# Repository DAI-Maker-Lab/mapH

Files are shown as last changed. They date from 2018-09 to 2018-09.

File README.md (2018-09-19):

<h1>mapH</h1>
mapH is a handheld georeferenced soil pH meter originally built as a demo for the 2018 Cracking the Nut conference. It was meant to illustrate potential applications of novel approaches to small-scale hardware development and production to climate smart agriculture in developing country contexts. It is based on the [DF Robot Analog Spear Tip pH sensor](https://www.dfrobot.com/product-1668.html), Arduino Pro Micro, and the Adafruit FONA 808.

It was just a proof-of-concept demo, so it's pretty rough. It uploads a CSV of the pH reading and the GPS coordinate to Pastebin where it can then be brought into a more useful analysis tool, like Mapbox or OpenGIS.

<h3>Usage</h3>
Turn the switch to the on position. When the green LED is lit and the red is off, the unit has a valid GPS fix and the user can take a sample. Place the soil probe into the soil to be sampled and press the button. The LEDs will flash while a series of 100 readings are very quickly taken and averaged. The red LED will light and the green will turn off, indicating that the reading is being transmitted to the server. When the green LED is lit, the unit is ready to take another sample.

<h3>Research Questions</h3>
mapH was developed as a demonstration of the potential of custom hardware to serve the needs of developing country users in the area of climate smart agriculture. It was developed on the hypothesis that awareness of the relative pH differences of farmers' fields could enable more efficient and effective application of fertilizers and other inputs. Similar tools, scaled for developed country farmers, are available commercially on the same principle (and a review of the literature on the effectiveness of these in practice would be interesting in itself).

Unanswered questions regarding the demo hardware might include:

* Does it in fact accurately read soil pH levels?
* Is this in fact useful when compared with other tools available to farmers, specifically in developing country contexts (i.e., smallholder farmers with limited capital infrastructure)?
* Are there modifications that would make the device more useful?
* What is the best protocol for using the device (in terms of cleaning and caring for the probe, calibration, choosing a sample site, depth of sample, etc.)?
* How might a farmer use the data from the tool to make changes to their farming practices?

<h3>Errata</h3>
The v0.1 design erroneously routed Pin 3 from the pH sensor to D12 on the Arduino; it should have gone to A0 as in the v0.2.

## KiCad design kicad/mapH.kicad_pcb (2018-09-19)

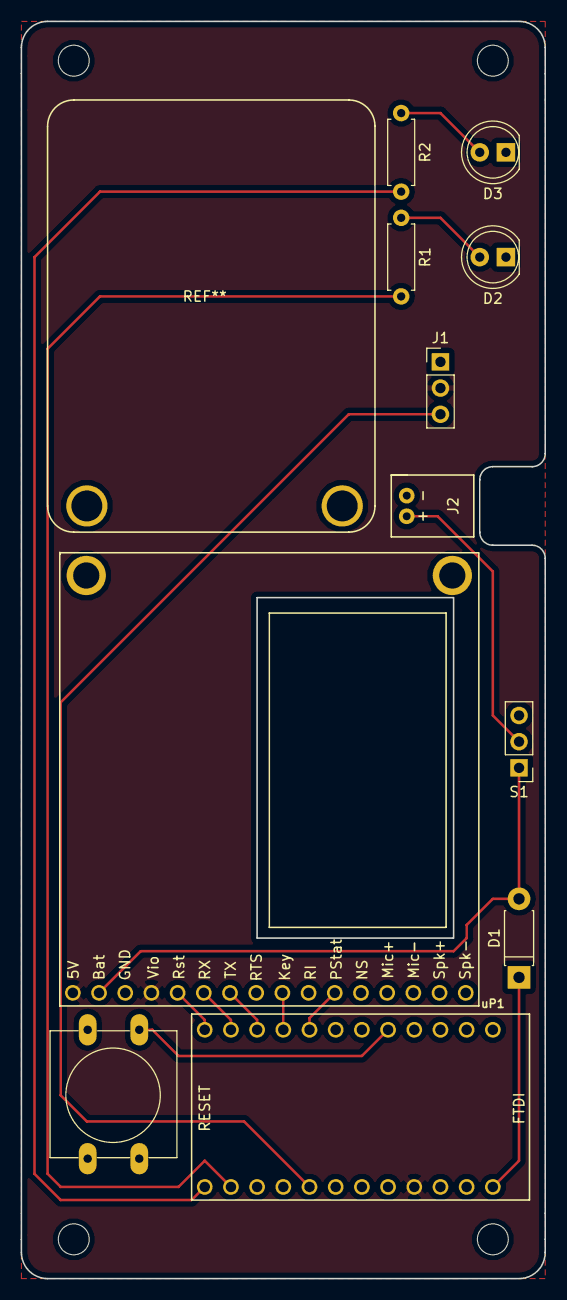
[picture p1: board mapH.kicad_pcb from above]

Board: 2 copper layers, 50.8 x 121.9 mm, 12 parts (1 on the bottom side), 16 nets.

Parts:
D1: D; D_DO-41_SOD81_P7.62mm_Horizontal
D2: RED; LED_D5.0mm_FlatTop
D3: GREEN; LED_D5.0mm_FlatTop
J1: DFRobot; Socket_Strip_Straight_1x03_Pitch2.54mm
J2: JST; JST-PH-2
R1, R2: R; R_Axial_DIN0207_L6.3mm_D2.5mm_P7.62mm_Horizontal
S1: Power; Socket_Strip_Straight_1x03_Pitch2.54mm
S2: DTS-3; SW_PUSH-12mm
U1: FONA_808
makerlabqr: makerlabqr
uP1: ARDUPROMINI-6; Arduino_Pro_Mini-6

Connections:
BAT+: D1.2, S1.1, U1.2
GND: D2.1, D3.1, J1.1, J2.2, S2.2, U1.3, uP1.10, uP1.20
INT0: S2.1, uP1.11
unnamed: D1.1, uP1.19
unnamed: D2.2, R1.1
unnamed: D3.2, R2.1
unnamed: J1.3, uP1.26
unnamed: J2.1, S1.2
unnamed: R1.2, uP1.29
unnamed: R2.2, uP1.30
unnamed: U1.5, uP1.18
unnamed: U1.6, uP1.17
unnamed: U1.7, uP1.16
unnamed: U1.9, uP1.15
unnamed: U1.11, uP1.14
VCC: J1.2, U1.1, U1.4, uP1.22

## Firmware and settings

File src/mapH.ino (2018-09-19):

#define VERSION 0.1
#define PASTEBINKEY   "b711cd2e1b2e5f08fa4f2f51c538dd6e"
#define PASTEBINUSER  "3189ffc48fa57d26e80f53382b156557"
#define UTCOFFSET   -6

// - - - - - - - - - - - - - - - - - - - - - - - - - - - - - - - - - - - - - - - - 

#include <Adafruit_FONA.h>    //  https://github.com/adafruit/Adafruit_FONA
#include <SoftwareSerial.h>   //  Standard software serial library

#define BUTTON 2              //  Button to send reading
#define FONA_PS 5             //  FONA power status pin
#define FONA_KEY 6            //  FONA Key pin
#define FONA_TX 7             //  UART pin from FONA
#define FONA_RX 8             //  UART pin to FONA
#define FONA_RST 9            //  FONA reset pin
#define GREEN 10              //  Green status LED
#define RED 11                //  Red status LED
#define PH_PIN A0             //  pH reading from DFRobot unit

boolean buttonPressed = false;
boolean fix = false;
unsigned long tick = 0;
unsigned long cadence = 10000;  //  ms between position updates

float latitude;
float longitude;

Adafruit_FONA fona = Adafruit_FONA (FONA_RST);
SoftwareSerial fonaSerial = SoftwareSerial (FONA_TX, FONA_RX);



static void buttonPress() {
  if(fix == true) {
    digitalWrite(GREEN, HIGH);
    digitalWrite(RED, HIGH);
    buttonPressed = true;
  }
}



void setup() {
  pinMode(BUTTON, INPUT_PULLUP);
  pinMode(FONA_KEY, OUTPUT);
  pinMode(FONA_RX, OUTPUT);
  pinMode(GREEN, OUTPUT);
  pinMode(RED, OUTPUT);

  digitalWrite(RED, HIGH);
  digitalWrite(GREEN, LOW);

  Serial.begin(57600);
  Serial.print(F("mapH v"));
  Serial.println(VERSION);
  Serial.print(__DATE__);   //  Compile data and time helps identify software uploads
  Serial.print(F(" "));
  Serial.println(__TIME__);

  fonaOn();

  fona.enableGPS(true);
  attachInterrupt(digitalPinToInterrupt(BUTTON), buttonPress, FALLING);
  interrupts();
}



void loop() {
  if(millis() > tick) {
    if(fona.GPSstatus() < 2) {
      fix = false;
    } else {
      fix = true;
    }
    tick = millis() + cadence;
  }

  //fix = true;     //  For indoor debugging

  if(buttonPressed == true) {
    sendReading();
    buttonPressed = false;
  }

  if(fix == true) {
    digitalWrite(GREEN, HIGH);
    digitalWrite(RED, LOW);
  } else {
    digitalWrite(GREEN, LOW);
    digitalWrite(RED, HIGH);
  }
}



boolean fonaOn() {
  if(digitalRead(FONA_PS) == LOW) {        //  If the FONA is off...
    Serial.print(F("Powering FONA on..."));
    while (digitalRead(FONA_PS) == LOW) {
      digitalWrite(FONA_KEY, LOW);  //  ...pulse the Key pin low...
      wait(500);
    }
    digitalWrite(FONA_KEY, HIGH);        //  ...and then return it to high
    Serial.println(F(" done."));
  }
  
  Serial.println(F("Initializing FONA..."));
  
  fonaSerial.begin(4800);                      //  Open a serial interface to FONA
  
  if(fona.begin(fonaSerial) == false) {        //  Start the FONA on serial interface
    Serial.println(F("FONA not found. Check wiring and power."));
    return false;
  } else {
    Serial.print(F("FONA online. "));
    
    unsigned long gsmTimeout = millis() + 30000;
    boolean gsmTimedOut = false;

    Serial.print(F("Waiting for GSM network... "));
    while(1) {
      byte network_status = fona.getNetworkStatus();
      if(network_status == 1 || network_status == 5) break;
      
      if(millis() >= gsmTimeout) {
        gsmTimedOut = true;
        break;
      }
      wait(250);
    }

    if(gsmTimedOut == true) {
      Serial.println(F("timed out. Check SIM card, antenna, and signal."));
      return false;
    } else {
      Serial.println(F("done."));
    }

    //  RSSI is a measure of signal strength -- higher is better; less than 10 is worrying
    byte rssi = fona.getRSSI();
    Serial.print(F("RSSI: "));
    Serial.println(rssi);

    wait(3000);    //  Give the network a moment

    //fona.setGPRSNetworkSettings(F("hologram"));    //  Set APN to your local carrier

    if(rssi > 5) {
      if(fona.enableGPRS(true) == false) {
        //  Sometimes enableGPRS() returns false even though it succeeded
        if(fona.GPRSstate() != 1) {
          for(byte GPRSattempts = 0; GPRSattempts < 5; GPRSattempts++) {
            Serial.println(F("Trying again..."));
            wait(2000);
            fona.enableGPRS(true);
            
            if(fona.GPRSstate() == 1) {
              Serial.println(F("GPRS is on."));
              break;
            } else {
              Serial.print(F("Failed to turn GPRS on... "));
            }
          }
        }
      }
    }
    else {
      Serial.println(F("Can't transmit, network signal strength is poor."));
      gsmTimedOut = true;
    }

    clockSet();
    
    return true;
  }
}



void flushFona() {
  // Read all available serial input from FONA to flush any pending data.
  while(fona.available()) {
    char c = fona.read();
    Serial.print(c);
  }
}



void fonaOff() {
  wait(5000);        //  Shorter delays yield unpredictable results

  //  We'll turn GPRS off first, just to have an orderly shutdown
  if(fona.enableGPRS(false) == false) {
    if(fona.GPRSstate() == 1) {
      Serial.println(F("Failed to turn GPRS off."));
    } else {
      Serial.println(F("GPRS is off."));
    }
  }

  wait(500);

  // Power down the FONA if it needs it
  if(digitalRead(FONA_PS) == HIGH) {     //  If the FONA is on...
    fona.sendCheckReply(F("AT+CPOWD=1"), F("OK")); //  ...send shutdown command...
    digitalWrite(FONA_KEY, HIGH);                  //  ...and set Key high
  }
}



void wait(unsigned int ms) { //  Non-blocking delay function
  unsigned long period = millis() + ms;
  while(millis() < period) {
    Serial.flush();
  }
}



boolean sendReading() {
  digitalWrite(RED, HIGH);
  digitalWrite(GREEN, LOW);
  
  char timeBuffer[23];
  uint8_t timestamp[7];
  float speed_kph, heading, speed_mph, altitude;

  fona.getTime(timeBuffer, 23);
  fona.getGPS(&latitude, &longitude, &speed_kph, &heading, &altitude);

  int i = 0;

  char *token;
  token = strtok(timeBuffer, " ,\"/.:-");
  while(token != NULL) {
    timestamp[i] = atoi(token);
    i++;
    token = strtok(NULL, " ,\"/.:-");
  }
  
  float pH = takeReading();

  char data[200];

  char latChar[10];
  char lonChar[10];
  char phChar[10];

  dtostrf(latitude, 8, 4, latChar);
  dtostrf(longitude, 8, 4, lonChar);
  dtostrf(pH, 5, 2, phChar);

  //  Construct the body of the POST request:
  if(timestamp[4] < 10) {   //  Add a leading zero if necessary
    sprintf(data, "api_dev_key=%s&api_user_key=%s&&api_option=paste&api_paste_code={\"lat\":\"%s\",\"lon\":\"%s\",\"pH\":\"%s\",\"timestamp\":\"%d/%d/%d %d:0%d\"}\r\n", PASTEBINKEY, PASTEBINUSER, latChar, lonChar, phChar, timestamp[0], timestamp[1],timestamp[2],timestamp[3],timestamp[4]);
  } else {
    sprintf(data, "api_dev_key=%s&api_user_key=%s&&api_option=paste&api_paste_code={\"lat\":\"%s\",\"lon\":\"%s\",\"pH\":\"%s\",\"timestamp\":\"%d/%d/%d %d:%d\"}\r\n", PASTEBINKEY, PASTEBINUSER, latChar, lonChar, phChar, timestamp[0], timestamp[1],timestamp[2],timestamp[3],timestamp[4]);
  }
  
  //  The stock fona.HTTP_POST_start FONA library sequence was working from the US but 
  //  not on the Cellcard network in Cambodia, so we'll construct the sequence ourselves:
  
  fona.sendCheckReply (F("AT+HTTPTERM"), F("OK"));
  fona.sendCheckReply (F("AT+HTTPINIT"), F("OK"));
  fona.sendCheckReply (F("AT+HTTPPARA=\"CID\",1"), F("OK"));
  fona.sendCheckReply (F("AT+HTTPPARA=\"UA\",\"FONA\""), F("OK"));
  fona.sendCheckReply (F("AT+HTTPPARA=\"URL\",\"pastebin.com/api/api_post.php\""), F("OK"));
  fona.sendCheckReply(F("AT+HTTPSSL=1"), F("OK"));    //  Pastebin requires SSL
  fona.HTTP_para (F("CONTENT"), F("application/x-www-form-urlencoded"));
  
  Serial.print (F("AT+HTTPDATA="));
  Serial.print (strlen (data));
  Serial.println (F(",10000"));
  
  fona.print (F("AT+HTTPDATA="));
  fona.print (strlen (data));
  fona.println (F(",10000"));
  fona.expectReply (F("DOWNLOAD"));
  
  Serial.println (data);
  fona.println (data);
  fona.expectReply (F("OK"));

  int method = 0;
  int statuscode = 0;
  int length = 0;
  
  fona.sendCheckReply (F("AT+HTTPACTION=1"), F("OK"));
  fona.readStringUntil (": ");

  //  For reasons that are not clear, AT+HTTPACTION in this context is returning an 
  //  inconsistent number of zeroes before starting the METHOD,STATUS,LENGTH sequence.
  //  We'll ignore any initial zeroes since we're executing a POST command (1).
  
  while (method == 0)
  {
    method = fona.parseInt();
  }
  
  statuscode = fona.parseInt();
  length = fona.parseInt();

  Serial.print (F("Status Code: "));
  Serial.println (statuscode);
  Serial.print (F("Length: "));
  Serial.println (length);
          
  fona.HTTP_POST_end();

  if (statuscode == 200)
  {
    Serial.println (F("Upload succeeded."));
    return true;
  }
  else
  {
    Serial.println (F("Upload appeared to fail."));
    return false;
  }
}



float takeReading() {
  boolean red = false;
  boolean green = true;

  int sampleSize = 100;
  unsigned long pHreading = 0;
  
  for(int i = 0; i < sampleSize; i++) {
    digitalWrite(RED, red);
    digitalWrite(GREEN, green);
    pHreading += analogRead(PH_PIN);
    wait(100);
    red != red;
    green != green;
  }

  pHreading = pHreading / sampleSize;    //  Average the readings
  float voltage = pHreading * (5.0 / 1023.0);

  digitalWrite(RED, LOW);
  digitalWrite(GREEN, LOW);

  return 3.5 * voltage;
}



void clockSet() {
  wait(1000);    //  Give time for any trailing data to come in from FONA

  fona.enableRTC(true);

  int netOffset;

  char theDate[17];

  Serial.println(F("Attempting to get time from GSM location service..."));

  flushFona();    //  Flush any trailing data

  fona.sendCheckReply(F("AT+CIPGSMLOC=2,1"), F("OK"));    //  Query GSM location service for time
  
  fona.parseInt();                    //  Ignore first int
  int secondInt = fona.parseInt();    //  Ignore second int -- necessary on some networks/towers
  int netYear = fona.parseInt();      //  Get the results -- GSMLOC year is 4-digit
  int netMonth = fona.parseInt();
  int netDay = fona.parseInt();
  int netHour = fona.parseInt();      //  GSMLOC is _supposed_ to get UTC; we will adjust
  int netMinute = fona.parseInt();
  int netSecond = fona.parseInt();    //  Our seconds may lag slightly, of course

  if(netYear < 2016 || netYear > 2050 || netHour > 23) { //  If that obviously didn't work...
    netSecond = netMinute;  //  ...shift everything up one to capture that second int
    netMinute = netHour;
    netHour = netDay;
    netDay = netMonth;
    netMonth = netYear;
    netYear = secondInt;

    Serial.println(F("Recombobulating..."));
  }

  if(netYear < 2016 || netYear > 2050 || netHour > 23) {   // If that still didn't work...
    Serial.println(F("GSM location service failed."));
    /*   ...the we'll get time from the NTP pool instead: 
     *  (https://en.wikipedia.org/wiki/Network_Time_Protocol)
     */
    fona.enableNTPTimeSync(true, F("0.daimakerlab.pool.ntp.org"));
    Serial.println(F("Attempting to enable NTP sync."));
    
    wait(15000);                 // Wait for NTP server response
    
    fona.println(F("AT+CCLK?")); // Query FONA's clock for resulting NTP time              
    netYear = fona.parseInt();    // Capture the results
    netMonth = fona.parseInt();
    netDay = fona.parseInt();
    netHour = fona.parseInt();    // We asked NTP for UTC and will adjust below
    netMinute = fona.parseInt();
    netSecond = fona.parseInt();  // Our seconds may lag slightly
  }

  if((netYear < 1000 && netYear >= 16 && netYear < 50) || (netYear > 1000 && netYear >= 2016 && netYear < 2050)) {
  //  If we got something that looks like a valid date...
    //  Adjust UTC to local time
    if((netHour + UTCOFFSET) < 0) {           //  If our offset + the UTC hour < 0...
      netHour = (24 + netHour + UTCOFFSET);   //  ...add 24...
      netDay = (netDay - 1);                  //  ...and adjust the date to UTC - 1
    } else {
      if((netHour + UTCOFFSET) > 23) {        //  If our offset + the UTC hour > 23...
        netHour = (netHour + UTCOFFSET - 24); //  ...subtract 24...
        netDay = (netDay + 1);                //  ...and adjust the date to UTC + 1
      } else {
        netHour = (netHour + UTCOFFSET);      //  Otherwise it's straight addition
      }
    }

    Serial.print(F("Obtained current time: "));
    sprintf(theDate, "%d/%d/%d %d:%d", netDay, netMonth, netYear, netHour, netMinute);
    Serial.println(theDate);

    //setTime(netHour, netMinute, netSecond, netDay, netMonth, netYear);   //set the system time to 23h31m30s on 13Feb2009
  } else {
    Serial.println(F("Didn't find reliable time. Will continue to use RTC's current time."));
  }

  wait(200);              //  Give FONA a moment to catch its breath
}
